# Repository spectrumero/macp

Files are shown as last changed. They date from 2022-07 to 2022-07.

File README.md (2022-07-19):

# ZX Make-a-Chip Pro

Back in the day, there was some software for the Sinclair Spectrum (often
advertised today as "VERY R@RE!!!!11" on eBay) called Make-a-Chip, by
Icognito Software Ltd. It waas a circuit simulator that allowed you to
build simple logic circuits with digital gates (AND, OR, NAND, NOR).

Today, of course, we can go many steps better; we have the FPGA (field
programmable gate array) to play with, and we can realise our own designs,
right up to entire systems on a chip.

2022 is the 40th anniversary of the launch of the Sinclair Spectrum, and
this project is something to celebrate that.

The ZX Make-a-Chip Pro is a board with a Lattice iCE40-HX4K FPGA with
all the level shifting required to connect to a Sinclair Spectrum.
It's designed to work with the open source IceStorm toolchain for
the FPGA used (but will no doubt work just fine with the Lattice
proprietary toolchain, too). Aside from the FPGA, it also has some
static ram (128k x 8, 256k x 8 or 512k x 8), the serial flash to 
hold the FPGA's "gateware" (with room left over for other uses),
a crystal oscillator, interface electronics for the 3.3v to 5v level
translation, and 25 GPIOs for connecting to other things.

## The PCB

A 4-layer PCB. This has been successfully made using PCBWay.

## Major parts

The FPGA is an iCE40-HX4K-TQ144. Unfortunately the HX1K has a sufficiently
different pinout that it won't work. When using arachne-pnr/nextpnr during
place and route, select "8k" as the device and "tq144:4k" as the package.
(In reality, the die in this chip is an HX8K)

Any JEDEC compliant SPI flash chip will work but it **must** support
the page program command. Check the datasheet before you commit to a chip.
While flash that doesn't support paged write will work, you won't be able
to program it with the `iceprog` tool - at least without modifying it to
work with a chip that doesn't support the page program command (and it's
doubtful you will be able to make it work at all with the Lattice
proprietary IDE).

Look for support for 'PP' (command 0x02) in the chip's datasheet.
The chip must also support 64kb block erase.

The gateware requires three 64kb blocks. This gets written to the first
three 64kb blocks. Remaining space in the flash may be used for projects 
(e.g. code), so as long as the flash is bigger than 192kbytes, it's good 
enough.

The RAM is on the 3.3v side of the board, so ensure that the static RAM
works with 3.3v (there are still quite a few 5v static RAM chips that won't
go down to 3.3v). The faster the better. If you only use the static RAM
for the Spectrum side then you can pretty much use any chip you please,
but if you're going to implement a second processor on the FPGA, you
probably want something fairly fast (10ns is available).

The crystal oscillator I use is 25MHz. If you choose a different value,
it's worth checking that it fits in the input limits of the FPGA's
PLL.

The remainder of the devices on the board should be pretty widely availble.

## Special symbols

There are two symbols unique to the project: the ZX edge connector
(designed for through hole mounting) and a schematic symbol for the
74ALVC164245PVG bus translator. The edge connector also has an associated
PCB footprint. See the local-lib directory.

## Programming other parts of the flash with iceprog

The icestorm toolchain's `iceprog` program can do more than just write
the gateware to the flash chip. You can supply it an offset, for example
if you want to store ROM code that will be used later by the FPGA
or copied to RAM, or a FatFS filesystem:

`iceprog -0 0x30000 file.bin`

to write the contents of a file from 0x30000 (the 64k block immediately
following the gateware).

## Recommended programming hardware

The Adafruit FT232H board works well (any similar board with this FTDI
chip should work with `iceprog`). Connect it as follows:

```
D0 -> SCK
D1 -> SDO
D2 -> SDI
D3 (not connected)
D4 -> SS
D5 (not connected)
D6 -> CDONE
D7 -> CRESET
```

You may need to invoke `iceprog` as follows:

`iceprog -d i:0x0403:0x6014 <filename>`

...if it fails to find your FT232H breakout board. (You may need `sudo`
as well).

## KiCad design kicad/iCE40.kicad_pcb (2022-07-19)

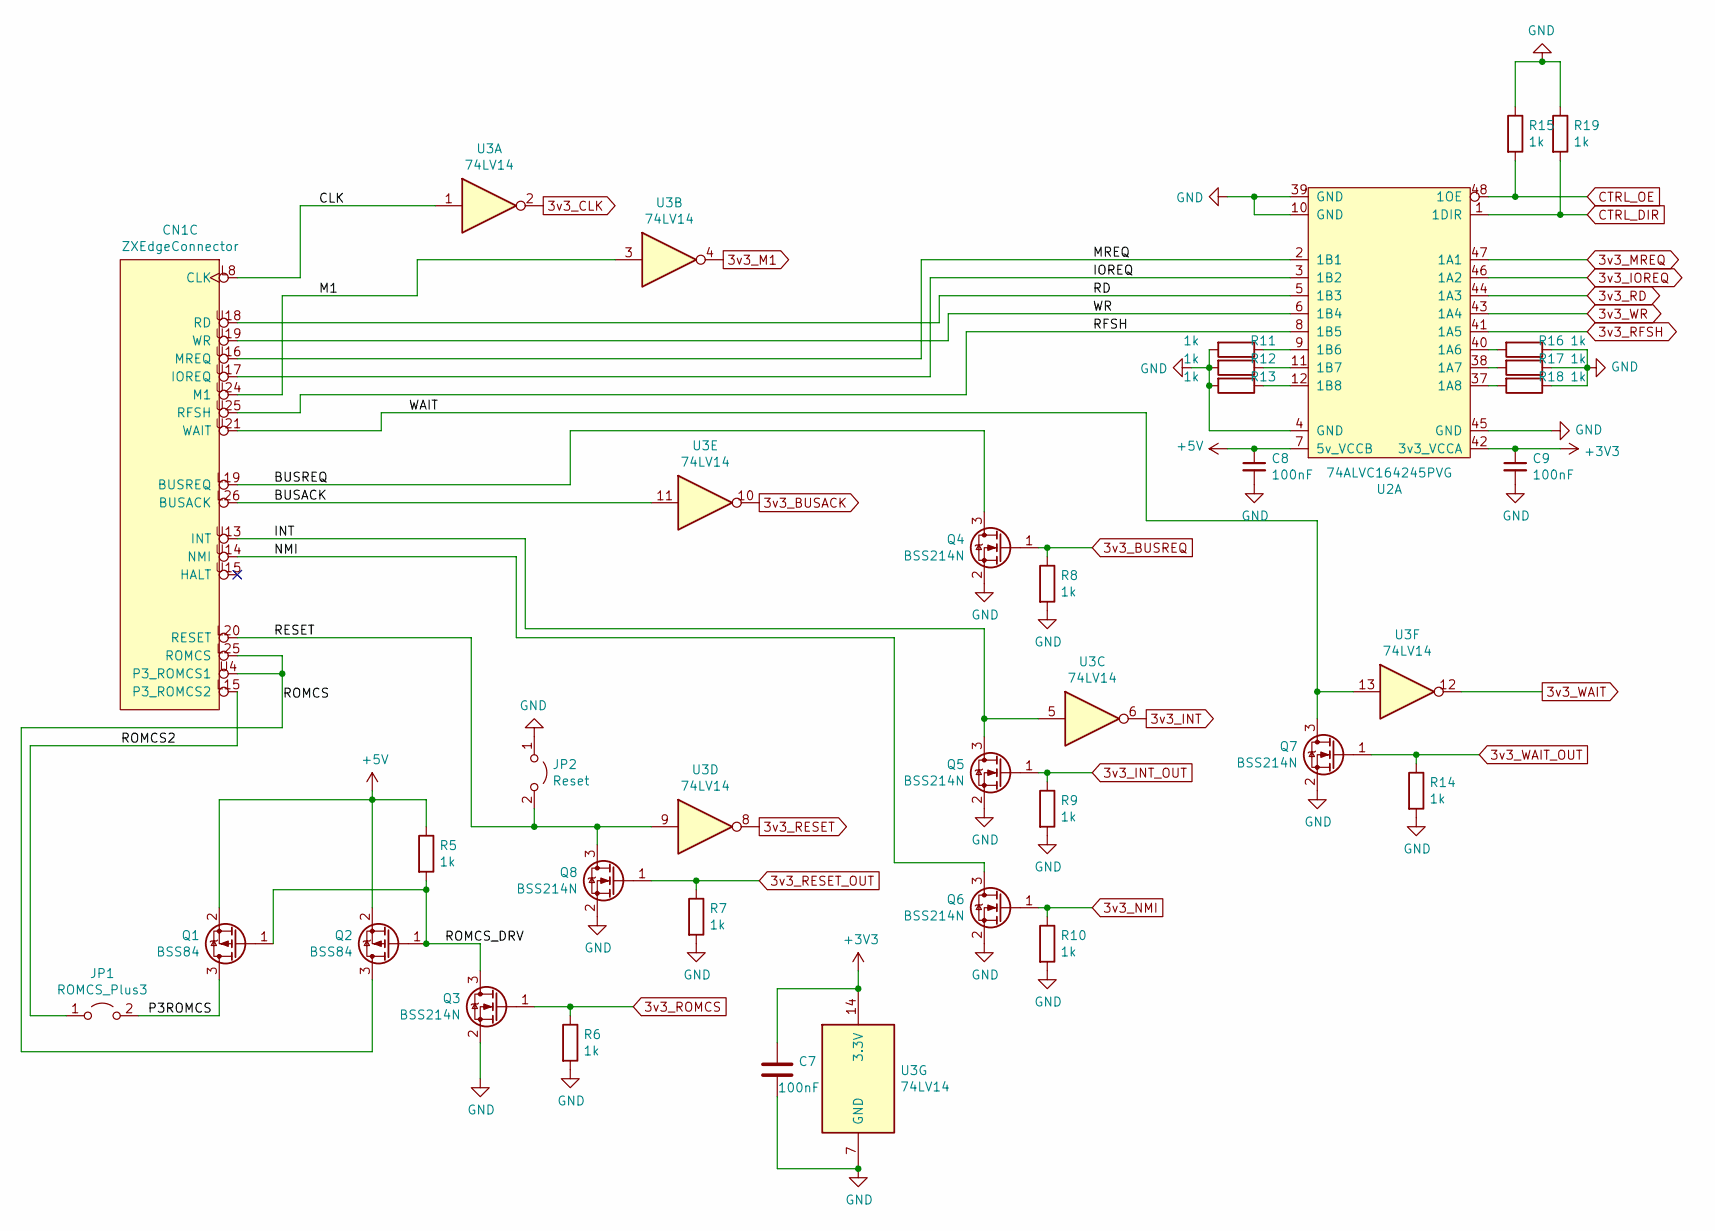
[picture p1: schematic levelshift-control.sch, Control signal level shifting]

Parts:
C7, C8, C9: 100nF; C_0603_1608Metric_Pad1.08x0.95mm_HandSolder
CN1: ZXEdgeConnector
JP1: ROMCS_Plus3; PinHeader_1x02_P2.54mm_Vertical
JP2: Reset; PinHeader_1x02_P2.54mm_Vertical
Q1, Q2: BSS84; SOT-23
Q3, Q4, Q5, Q6, Q7, Q8: BSS214N; SOT-23
R5, R6, R7, R8, R9, R10, R11, R12, R13, R14, R15, R16, R17, R18, R19: 1k; R_0603_1608Metric_Pad0.98x0.95mm_HandSolder
U2: 74ALVC164245PVG; SSOP-48_7.5x15.9mm_P0.635mm
U3: 74LV14; SOIC-14_3.9x8.7mm_P1.27mm

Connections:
3v3_BUSACK: U3.10; also elsewhere on the board
3v3_BUSREQ: Q4.1 (G), R8.1; also elsewhere on the board
3v3_CLK: U3.2; also elsewhere on the board
3v3_INT: U3.6; also elsewhere on the board
3v3_INT_OUT: Q5.1 (G), R9.1; also elsewhere on the board
3v3_IOREQ: U2.46 (1A2); also elsewhere on the board
3v3_M1: U3.4; also elsewhere on the board
3v3_MREQ: U2.47 (1A1); also elsewhere on the board
3v3_NMI: Q6.1 (G), R10.1; also elsewhere on the board
3v3_RD: U2.44 (1A3); also elsewhere on the board
3v3_RESET: U3.8; also elsewhere on the board
3v3_RESET_OUT: Q8.1 (G), R7.1; also elsewhere on the board
3v3_RFSH: U2.41 (1A5); also elsewhere on the board
3v3_ROMCS: Q3.1 (G), R6.1; also elsewhere on the board
3v3_WAIT: U3.12; also elsewhere on the board
3v3_WAIT_OUT: Q7.1 (G), R14.1; also elsewhere on the board
3v3_WR: U2.43 (1A4); also elsewhere on the board
+3V3: C7.1, C9.1, U2.42 (3v3_VCCA), U3.14 (3.3V); also elsewhere on the board
+5V: C8.1, Q1.2 (S), Q2.2 (S), R5.1, U2.7 (5v_VCCB); also elsewhere on the board
/levelshift-control/BUSACK: CN1.L26 (BUSACK), U3.11
/levelshift-control/BUSREQ: CN1.L19 (BUSREQ), Q4.3 (D)
/levelshift-control/CLK: CN1.L8 (CLK), U3.1
/levelshift-control/INT: CN1.U13 (INT), Q5.3 (D), U3.5
/levelshift-control/IOREQ: CN1.U17 (IOREQ), U2.3 (1B2)
/levelshift-control/M1: CN1.U24 (M1), U3.3
/levelshift-control/MREQ: CN1.U16 (MREQ), U2.2 (1B1)
/levelshift-control/NMI: CN1.U14 (NMI), Q6.3 (D)
/levelshift-control/P3ROMCS: JP1.2 (B), Q1.3 (D)
/levelshift-control/RD: CN1.U18 (RD), U2.5 (1B3)
/levelshift-control/RESET: CN1.L20 (RESET), JP2.2 (B), Q8.3 (D), U3.9
/levelshift-control/RFSH: CN1.U25 (RFSH), U2.8 (1B5)
/levelshift-control/ROMCS: CN1.L25 (ROMCS), CN1.U4 (P3_ROMCS1), Q2.3 (D)
/levelshift-control/ROMCS2: CN1.L15 (P3_ROMCS2), JP1.1 (A)
/levelshift-control/ROMCS_DRV: Q1.1 (G), Q2.1 (G), Q3.3 (D), R5.2
/levelshift-control/WAIT: CN1.U21 (WAIT), Q7.3 (D), U3.13
/levelshift-control/WR: CN1.U19 (WR), U2.6 (1B4)
CTRL_DIR: R19.2, U2.1 (1DIR); also elsewhere on the board
CTRL_OE: R15.2, U2.48 (1OE); also elsewhere on the board
GND: C7.2, C8.2, C9.2, JP2.1 (A), Q3.2 (S), Q4.2 (S), Q5.2 (S), Q6.2 (S), Q7.2 (S), Q8.2 (S), R6.2, R7.2, R8.2, R9.2, R10.2, R11.2, R12.2, R13.2, R14.2, R15.1, R16.1, R17.1, R18.1, R19.1, U2.4 (GND), U2.10 (GND), U2.39 (GND), U2.45 (GND), U3.7 (GND); also elsewhere on the board
unnamed: R11.1, U2.9 (1B6)
unnamed: R12.1, U2.11 (1B7)
unnamed: R13.1, U2.12 (1B8)
unnamed: R16.2, U2.40 (1A6)
unnamed: R17.2, U2.38 (1A7)
unnamed: R18.2, U2.37 (1A8)

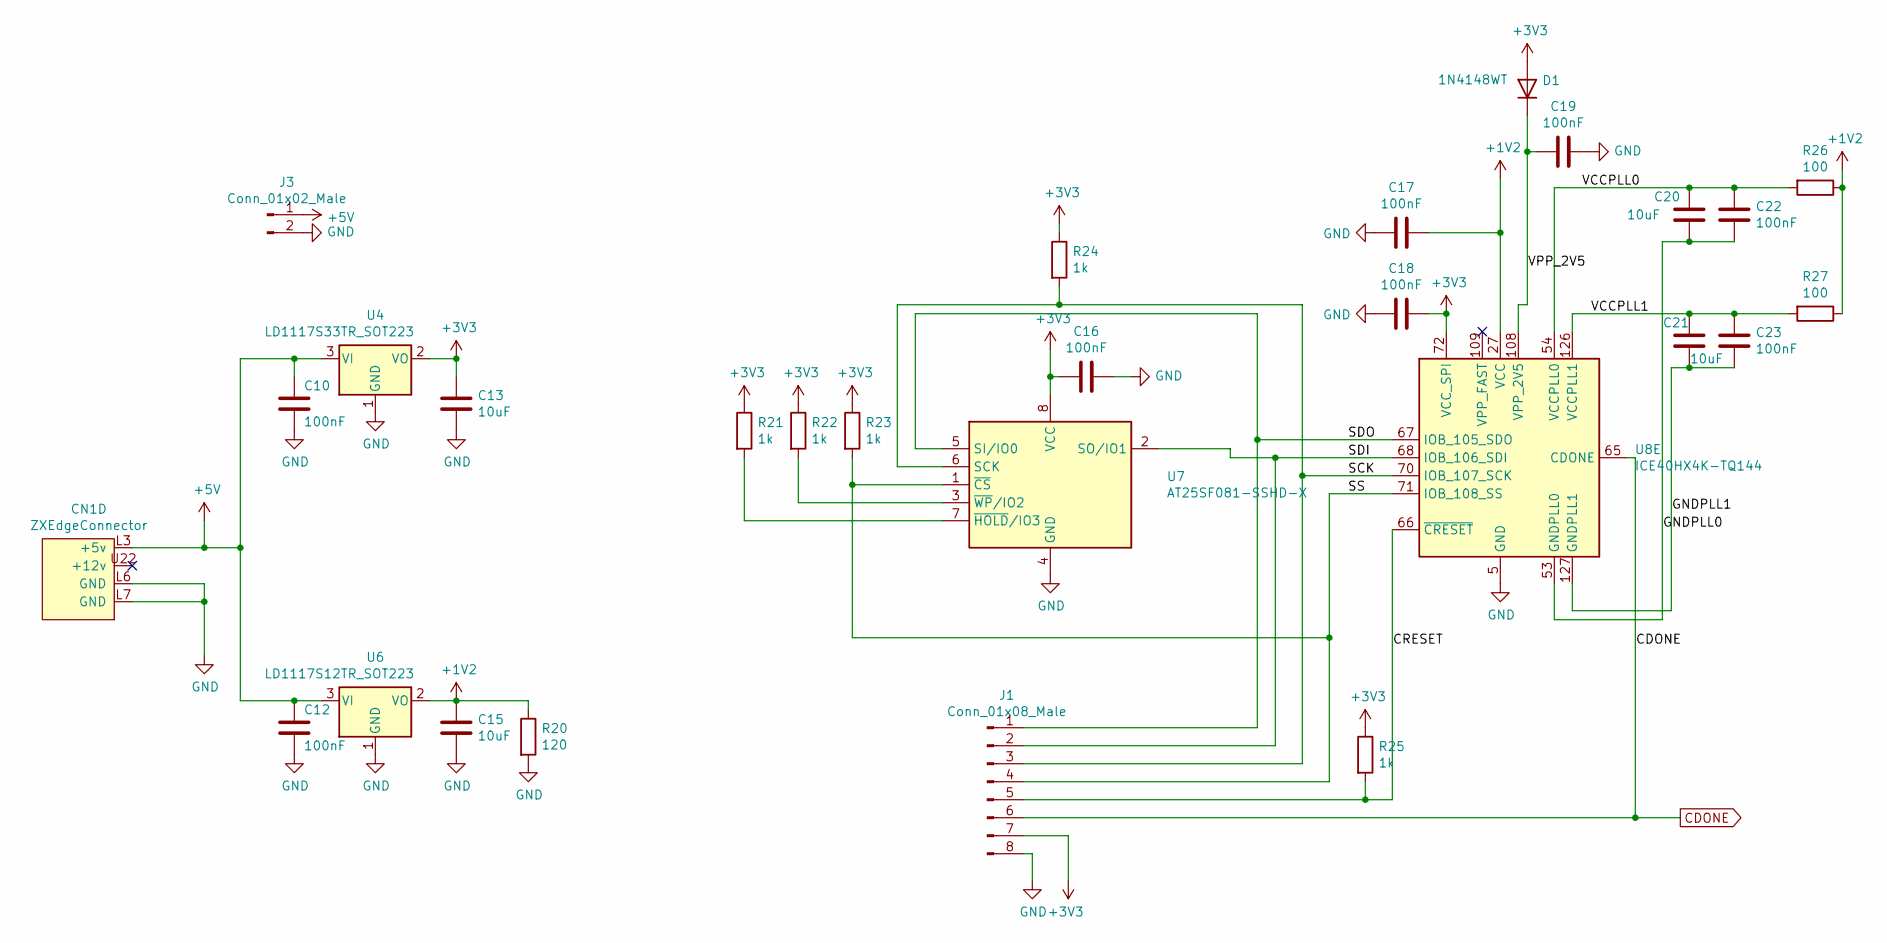
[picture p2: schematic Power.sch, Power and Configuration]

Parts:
C10, C12, C16, C17, C18, C19, C22, C23: 100nF; C_0603_1608Metric_Pad1.08x0.95mm_HandSolder
C13, C15, C20, C21: 10uF; C_0805_2012Metric_Pad1.18x1.45mm_HandSolder
CN1: ZXEdgeConnector
D1: 1N4148WT; D_SOD-523
J1: Conn_01x08_Male; PinHeader_1x08_P2.54mm_Vertical
J3: Conn_01x02_Male; PinHeader_1x02_P2.54mm_Vertical
R20: 120; R_0603_1608Metric_Pad0.98x0.95mm_HandSolder
R21, R22, R23, R24, R25: 1k; R_0603_1608Metric_Pad0.98x0.95mm_HandSolder
R26, R27: 100; R_0603_1608Metric_Pad0.98x0.95mm_HandSolder
U4: LD1117S33TR_SOT223; SOT-223-3_TabPin2
U6: LD1117S12TR_SOT223; SOT-223-3_TabPin2
U7: AT25SF081-SSHD-X; SOIC-8_3.9x4.9mm_P1.27mm
U8: ICE40HX4K-TQ144; TQFP-144_20x20mm_P0.5mm

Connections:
+1V2: C15.1, C17.1, R20.1, R26.1, R27.1, U6.2 (VO), U8.27 (VCC), U8.40 (VCC), U8.92 (VCC), U8.111 (VCC)
+3V3: C13.1, C16.2, C18.1, D1.2 (A), J1.7, R21.1, R22.1, R23.1, R24.1, R25.1, U4.2 (VO), U7.8 (VCC), U8.72 (VCC_SPI); also elsewhere on the board
+5V: C10.1, C12.1, CN1.L3 (+5v), J3.1, U4.3 (VI), U6.3 (VI); also elsewhere on the board
/Power And Config/CRESET: J1.5, R25.2, U8.66 (~CRESET)
/Power And Config/GNDPLL0: C20.2, C22.2, U8.53 (GNDPLL0)
/Power And Config/GNDPLL1: C21.2, C23.2, U8.127 (GNDPLL1)
/Power And Config/SCK: J1.3, R24.2, U7.6 (SCK), U8.70 (IOB_107_SCK)
/Power And Config/SDI: J1.2, U7.2 (SO/IO1), U8.68 (IOB_106_SDI)
/Power And Config/SDO: J1.1, U7.5 (SI/IO0), U8.67 (IOB_105_SDO)
/Power And Config/SS: J1.4, R23.2, U7.1 (~CS), U8.71 (IOB_108_SS)
/Power And Config/VCCPLL0: C20.1, C22.1, R26.2, U8.54 (VCCPLL0)
/Power And Config/VCCPLL1: C21.1, C23.1, R27.2, U8.126 (VCCPLL1)
/Power And Config/VPP_2V5: C19.2, D1.1 (K), U8.108 (VPP_2V5)
CDONE: J1.6, U8.65 (CDONE)
GND: C10.2, C12.2, C13.2, C15.2, C16.1, C17.2, C18.2, C19.1, CN1.L6 (GND), CN1.L7 (GND), J1.8, J3.2, R20.2, U4.1 (GND), U6.1 (GND), U7.4 (GND), U8.5 (GND), U8.13 (GND), U8.14 (GND), U8.59 (GND), U8.69 (GND), U8.86 (GND), U8.103 (GND), U8.132 (GND), U8.140 (GND); also elsewhere on the board
unnamed: R21.2, U7.7 (~HOLD~/IO3)
unnamed: R22.2, U7.3 (~WP~/IO2)

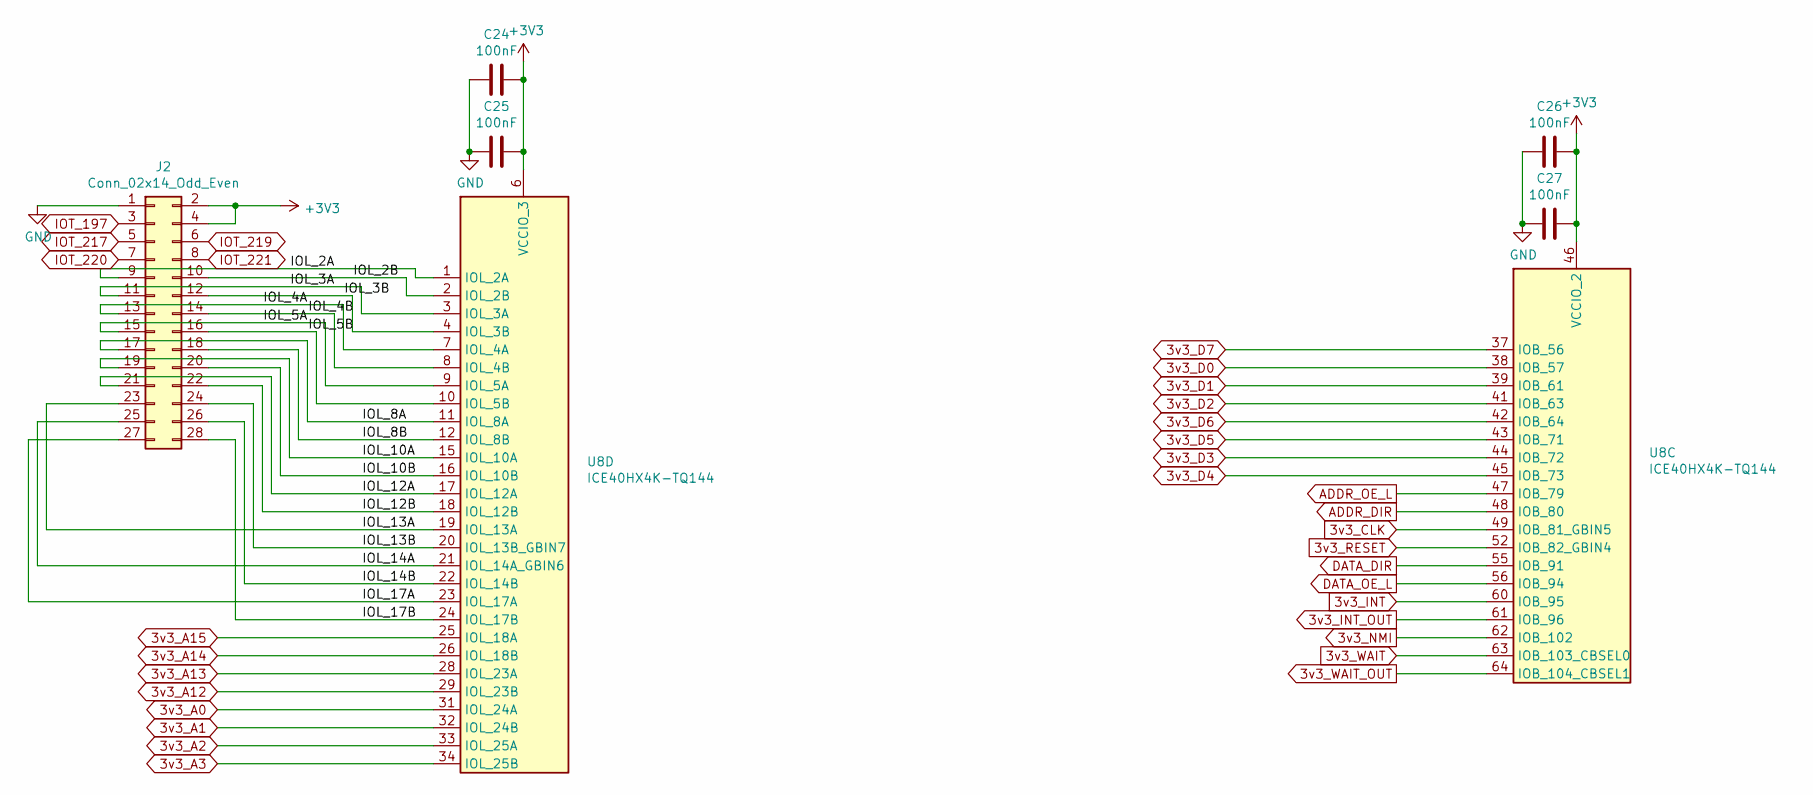
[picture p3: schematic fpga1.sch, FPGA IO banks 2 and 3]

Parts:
C24, C25, C26, C27: 100nF; C_0603_1608Metric_Pad1.08x0.95mm_HandSolder
J2: Conn_02x14_Odd_Even; PinHeader_2x14_P2.54mm_Vertical
U8: ICE40HX4K-TQ144; TQFP-144_20x20mm_P0.5mm

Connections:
3v3_A0: U8.31 (IOL_24A); also elsewhere on the board
3v3_A1: U8.32 (IOL_24B); also elsewhere on the board
3v3_A2: U8.33 (IOL_25A); also elsewhere on the board
3v3_A3: U8.34 (IOL_25B); also elsewhere on the board
3v3_A12: U8.29 (IOL_23B); also elsewhere on the board
3v3_A13: U8.28 (IOL_23A); also elsewhere on the board
3v3_A14: U8.26 (IOL_18B); also elsewhere on the board
3v3_A15: U8.25 (IOL_18A); also elsewhere on the board
3v3_CLK: U8.49 (IOB_81_GBIN5); also elsewhere on the board
3v3_D0: U8.38 (IOB_57); also elsewhere on the board
3v3_D1: U8.39 (IOB_61); also elsewhere on the board
3v3_D2: U8.41 (IOB_63); also elsewhere on the board
3v3_D3: U8.44 (IOB_72); also elsewhere on the board
3v3_D4: U8.45 (IOB_73); also elsewhere on the board
3v3_D5: U8.43 (IOB_71); also elsewhere on the board
3v3_D6: U8.42 (IOB_64); also elsewhere on the board
3v3_D7: U8.37 (IOB_56); also elsewhere on the board
3v3_INT: U8.60 (IOB_95); also elsewhere on the board
3v3_INT_OUT: U8.61 (IOB_96); also elsewhere on the board
3v3_NMI: U8.62 (IOB_102); also elsewhere on the board
3v3_RESET: U8.52 (IOB_82_GBIN4); also elsewhere on the board
3v3_WAIT: U8.63 (IOB_103_CBSEL0); also elsewhere on the board
3v3_WAIT_OUT: U8.64 (IOB_104_CBSEL1); also elsewhere on the board
+3V3: C24.1, C25.2, C26.1, C27.2, J2.2, J2.4, U8.6 (VCCIO_3), U8.30 (VCCIO_3), U8.46 (VCCIO_2), U8.57 (VCCIO_2); also elsewhere on the board
/FPGA1/IOL_2A: J2.9, U8.1 (IOL_2A)
/FPGA1/IOL_2B: J2.10, U8.2 (IOL_2B)
/FPGA1/IOL_3A: J2.11, U8.3 (IOL_3A)
/FPGA1/IOL_3B: J2.12, U8.4 (IOL_3B)
/FPGA1/IOL_4A: J2.13, U8.7 (IOL_4A)
/FPGA1/IOL_4B: J2.14, U8.8 (IOL_4B)
/FPGA1/IOL_5A: J2.15, U8.9 (IOL_5A)
/FPGA1/IOL_5B: J2.16, U8.10 (IOL_5B)
/FPGA1/IOL_8A: J2.17, U8.11 (IOL_8A)
/FPGA1/IOL_8B: J2.18, U8.12 (IOL_8B)
/FPGA1/IOL_10A: J2.19, U8.15 (IOL_10A)
/FPGA1/IOL_10B: J2.20, U8.16 (IOL_10B)
/FPGA1/IOL_12A: J2.21, U8.17 (IOL_12A)
/FPGA1/IOL_12B: J2.22, U8.18 (IOL_12B)
/FPGA1/IOL_13A: J2.23, U8.19 (IOL_13A)
/FPGA1/IOL_13B: J2.24, U8.20 (IOL_13B_GBIN7)
/FPGA1/IOL_14A: J2.25, U8.21 (IOL_14A_GBIN6)
/FPGA1/IOL_14B: J2.26, U8.22 (IOL_14B)
/FPGA1/IOL_17A: J2.27, U8.23 (IOL_17A)
/FPGA1/IOL_17B: J2.28, U8.24 (IOL_17B)
ADDR_DIR: U8.48 (IOB_80); also elsewhere on the board
ADDR_OE_L: U8.47 (IOB_79); also elsewhere on the board
DATA_DIR: U8.55 (IOB_91); also elsewhere on the board
DATA_OE_L: U8.56 (IOB_94); also elsewhere on the board
GND: C24.2, C25.1, C26.2, C27.1, J2.1; also elsewhere on the board
IOT_197: J2.3; also elsewhere on the board
IOT_217: J2.5; also elsewhere on the board
IOT_219: J2.6; also elsewhere on the board
IOT_220: J2.7; also elsewhere on the board
IOT_221: J2.8; also elsewhere on the board

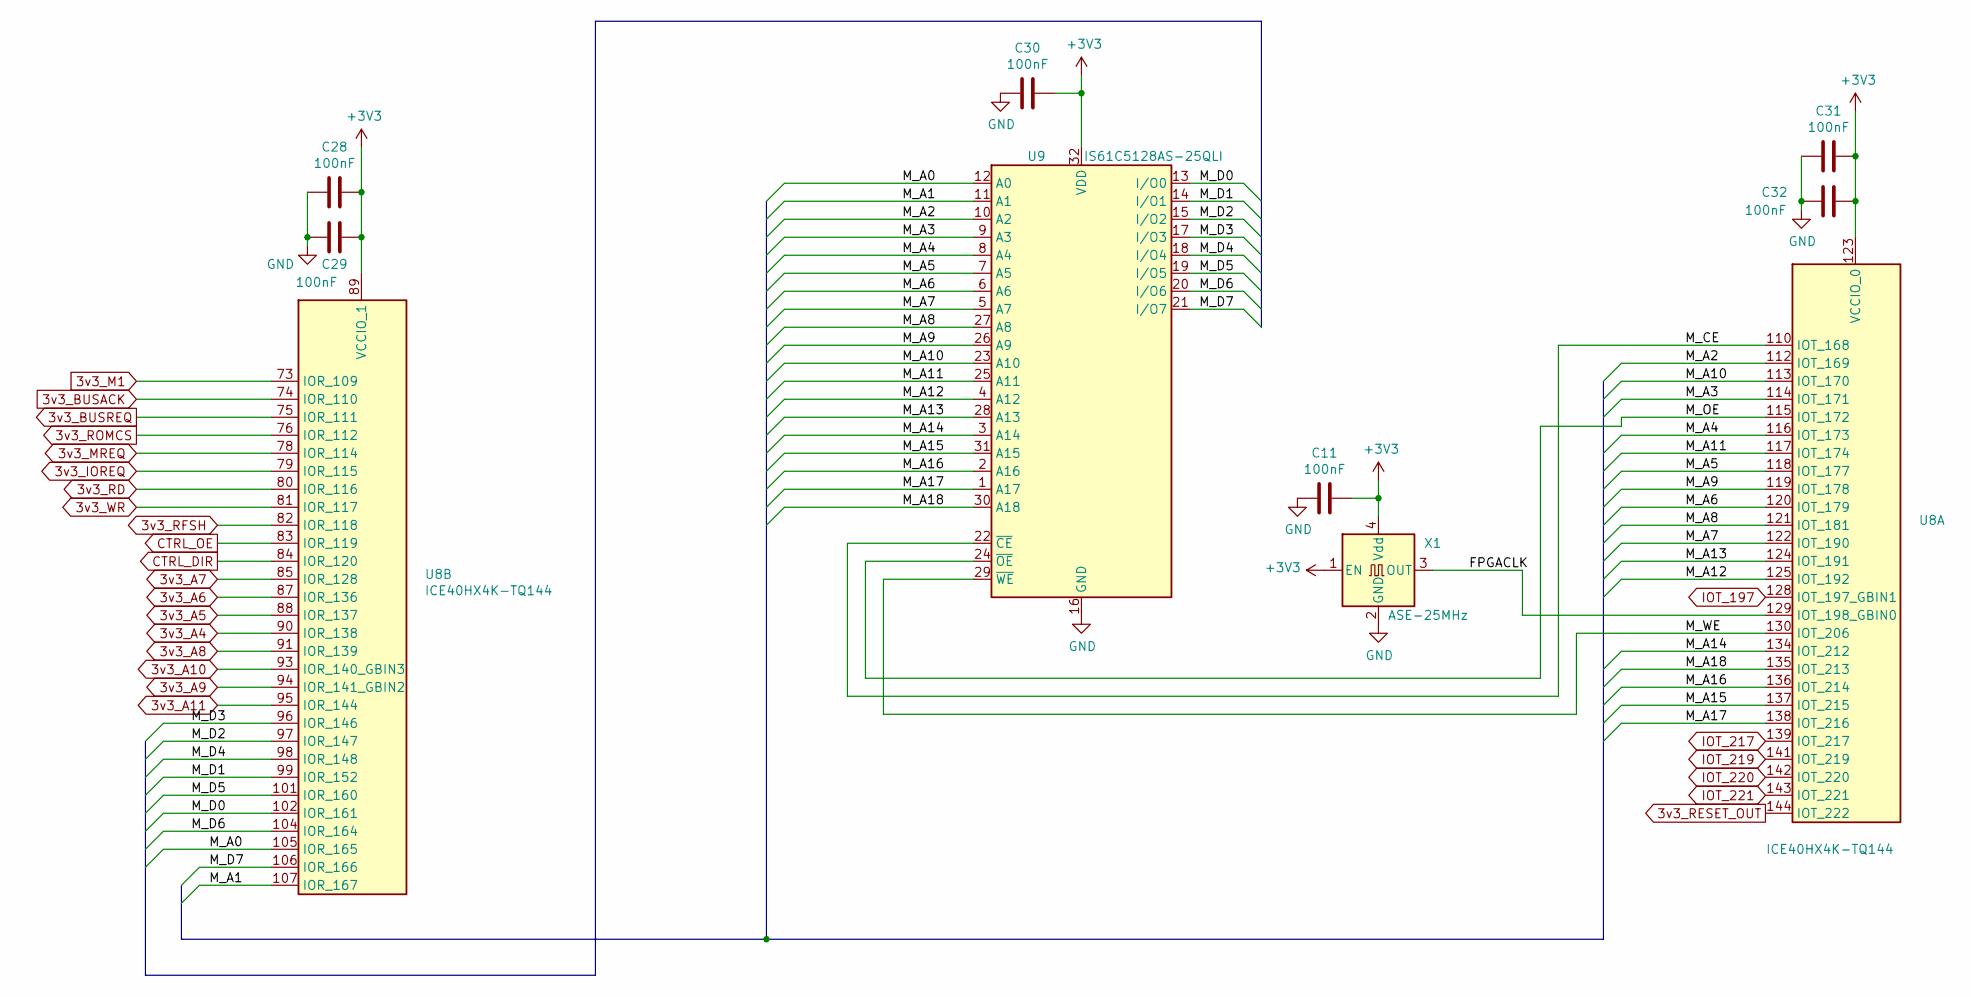
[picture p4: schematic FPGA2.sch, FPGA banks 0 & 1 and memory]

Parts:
C11, C28, C29, C30, C31, C32: 100nF; C_0603_1608Metric_Pad1.08x0.95mm_HandSolder
U8: ICE40HX4K-TQ144; TQFP-144_20x20mm_P0.5mm
U9: IS61C5128AS-25QLI; SSOP-32_11.305x20.495mm_P1.27mm
X1: ASE-25MHz; Oscillator_SMD_Abracon_ASE-4Pin_3.2x2.5mm

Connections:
3v3_A4: U8.90 (IOR_138); also elsewhere on the board
3v3_A5: U8.88 (IOR_137); also elsewhere on the board
3v3_A6: U8.87 (IOR_136); also elsewhere on the board
3v3_A7: U8.85 (IOR_128); also elsewhere on the board
3v3_A8: U8.91 (IOR_139); also elsewhere on the board
3v3_A9: U8.94 (IOR_141_GBIN2); also elsewhere on the board
3v3_A10: U8.93 (IOR_140_GBIN3); also elsewhere on the board
3v3_A11: U8.95 (IOR_144); also elsewhere on the board
3v3_BUSACK: U8.74 (IOR_110); also elsewhere on the board
3v3_BUSREQ: U8.75 (IOR_111); also elsewhere on the board
3v3_IOREQ: U8.79 (IOR_115); also elsewhere on the board
3v3_M1: U8.73 (IOR_109); also elsewhere on the board
3v3_MREQ: U8.78 (IOR_114); also elsewhere on the board
3v3_RD: U8.80 (IOR_116); also elsewhere on the board
3v3_RESET_OUT: U8.144 (IOT_222); also elsewhere on the board
3v3_RFSH: U8.82 (IOR_118); also elsewhere on the board
3v3_ROMCS: U8.76 (IOR_112); also elsewhere on the board
3v3_WR: U8.81 (IOR_117); also elsewhere on the board
+3V3: C11.1, C28.1, C29.1, C30.1, C31.1, C32.1, U8.89 (VCCIO_1), U8.100 (VCCIO_1), U8.123 (VCCIO_0), U8.131 (VCCIO_0), U9.32 (VDD), X1.1 (EN), X1.4 (Vdd); also elsewhere on the board
/FPGA2/FPGACLK: U8.129 (IOT_198_GBIN0), X1.3 (OUT)
/FPGA2/M_A0: U8.105 (IOR_165), U9.12 (A0)
/FPGA2/M_A1: U8.107 (IOR_167), U9.11 (A1)
/FPGA2/M_A2: U8.112 (IOT_169), U9.10 (A2)
/FPGA2/M_A3: U8.114 (IOT_171), U9.9 (A3)
/FPGA2/M_A4: U8.116 (IOT_173), U9.8 (A4)
/FPGA2/M_A5: U8.118 (IOT_177), U9.7 (A5)
/FPGA2/M_A6: U8.120 (IOT_179), U9.6 (A6)
/FPGA2/M_A7: U8.122 (IOT_190), U9.5 (A7)
/FPGA2/M_A8: U8.121 (IOT_181), U9.27 (A8)
/FPGA2/M_A9: U8.119 (IOT_178), U9.26 (A9)
/FPGA2/M_A10: U8.113 (IOT_170), U9.23 (A10)
/FPGA2/M_A11: U8.117 (IOT_174), U9.25 (A11)
/FPGA2/M_A12: U8.125 (IOT_192), U9.4 (A12)
/FPGA2/M_A13: U8.124 (IOT_191), U9.28 (A13)
/FPGA2/M_A14: U8.134 (IOT_212), U9.3 (A14)
/FPGA2/M_A15: U8.137 (IOT_215), U9.31 (A15)
/FPGA2/M_A16: U8.136 (IOT_214), U9.2 (A16)
/FPGA2/M_A17: U8.138 (IOT_216), U9.1 (A17)
/FPGA2/M_A18: U8.135 (IOT_213), U9.30 (A18)
/FPGA2/M_CE: U8.110 (IOT_168), U9.22 (~CE)
/FPGA2/M_D0: U8.102 (IOR_161), U9.13 (I/O0)
/FPGA2/M_D1: U8.99 (IOR_152), U9.14 (I/O1)
/FPGA2/M_D2: U8.97 (IOR_147), U9.15 (I/O2)
/FPGA2/M_D3: U8.96 (IOR_146), U9.17 (I/O3)
/FPGA2/M_D4: U8.98 (IOR_148), U9.18 (I/O4)
/FPGA2/M_D5: U8.101 (IOR_160), U9.19 (I/O5)
/FPGA2/M_D6: U8.104 (IOR_164), U9.20 (I/O6)
/FPGA2/M_D7: U8.106 (IOR_166), U9.21 (I/O7)
/FPGA2/M_OE: U8.115 (IOT_172), U9.24 (~OE)
/FPGA2/M_WE: U8.130 (IOT_206), U9.29 (~WE)
CTRL_DIR: U8.84 (IOR_120); also elsewhere on the board
CTRL_OE: U8.83 (IOR_119); also elsewhere on the board
GND: C11.2, C28.2, C29.2, C30.2, C31.2, C32.2, U9.16 (GND), X1.2 (GND); also elsewhere on the board
IOT_197: U8.128 (IOT_197_GBIN1); also elsewhere on the board
IOT_217: U8.139 (IOT_217); also elsewhere on the board
IOT_219: U8.141 (IOT_219); also elsewhere on the board
IOT_220: U8.142 (IOT_220); also elsewhere on the board
IOT_221: U8.143 (IOT_221); also elsewhere on the board

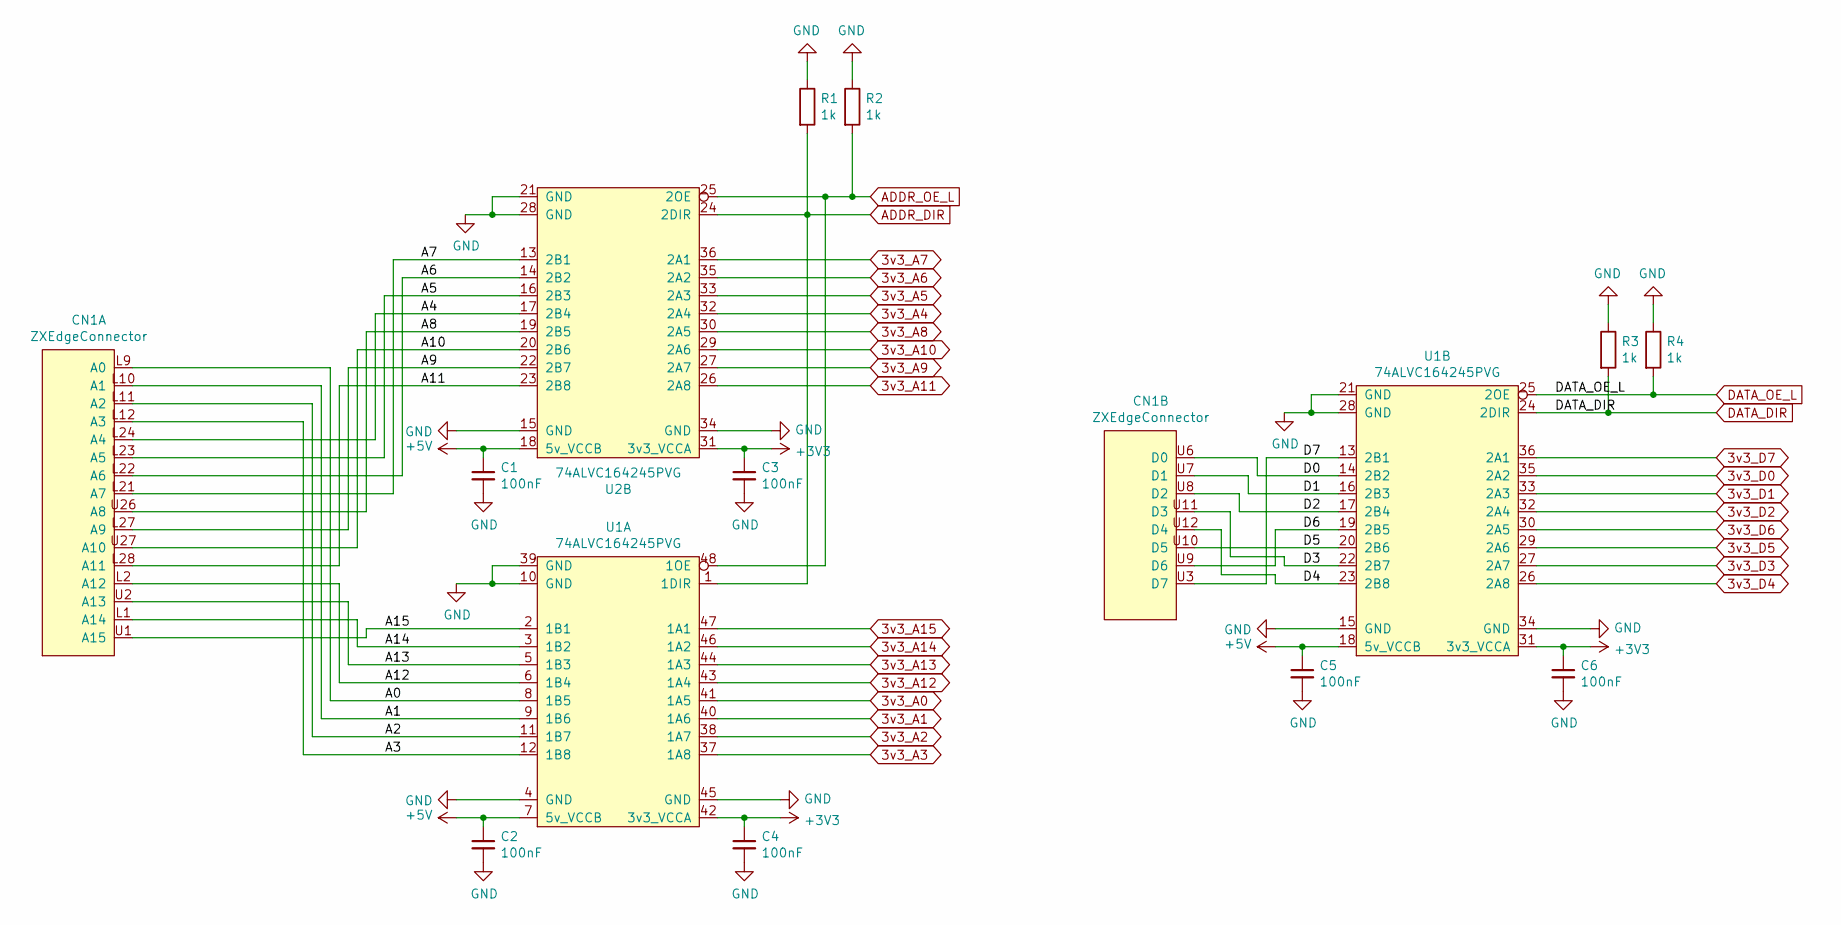
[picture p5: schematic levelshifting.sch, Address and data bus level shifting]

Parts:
C1, C2, C3, C4, C5, C6: 100nF; C_0603_1608Metric_Pad1.08x0.95mm_HandSolder
CN1: ZXEdgeConnector
R1, R2, R3, R4: 1k; R_0603_1608Metric_Pad0.98x0.95mm_HandSolder
U1, U2: 74ALVC164245PVG; SSOP-48_7.5x15.9mm_P0.635mm

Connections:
3v3_A0: U1.41 (1A5); also elsewhere on the board
3v3_A1: U1.40 (1A6); also elsewhere on the board
3v3_A2: U1.38 (1A7); also elsewhere on the board
3v3_A3: U1.37 (1A8); also elsewhere on the board
3v3_A4: U2.32 (2A4); also elsewhere on the board
3v3_A5: U2.33 (2A3); also elsewhere on the board
3v3_A6: U2.35 (2A2); also elsewhere on the board
3v3_A7: U2.36 (2A1); also elsewhere on the board
3v3_A8: U2.30 (2A5); also elsewhere on the board
3v3_A9: U2.27 (2A7); also elsewhere on the board
3v3_A10: U2.29 (2A6); also elsewhere on the board
3v3_A11: U2.26 (2A8); also elsewhere on the board
3v3_A12: U1.43 (1A4); also elsewhere on the board
3v3_A13: U1.44 (1A3); also elsewhere on the board
3v3_A14: U1.46 (1A2); also elsewhere on the board
3v3_A15: U1.47 (1A1); also elsewhere on the board
3v3_D0: U1.35 (2A2); also elsewhere on the board
3v3_D1: U1.33 (2A3); also elsewhere on the board
3v3_D2: U1.32 (2A4); also elsewhere on the board
3v3_D3: U1.27 (2A7); also elsewhere on the board
3v3_D4: U1.26 (2A8); also elsewhere on the board
3v3_D5: U1.29 (2A6); also elsewhere on the board
3v3_D6: U1.30 (2A5); also elsewhere on the board
3v3_D7: U1.36 (2A1); also elsewhere on the board
+3V3: C3.1, C4.1, C6.1, U1.31 (3v3_VCCA), U1.42 (3v3_VCCA), U2.31 (3v3_VCCA); also elsewhere on the board
+5V: C1.1, C2.1, C5.1, U1.7 (5v_VCCB), U1.18 (5v_VCCB), U2.18 (5v_VCCB); also elsewhere on the board
/levelshifting/A0: CN1.L9 (A0), U1.8 (1B5)
/levelshifting/A1: CN1.L10 (A1), U1.9 (1B6)
/levelshifting/A2: CN1.L11 (A2), U1.11 (1B7)
/levelshifting/A3: CN1.L12 (A3), U1.12 (1B8)
/levelshifting/A4: CN1.L24 (A4), U2.17 (2B4)
/levelshifting/A5: CN1.L23 (A5), U2.16 (2B3)
/levelshifting/A6: CN1.L22 (A6), U2.14 (2B2)
/levelshifting/A7: CN1.L21 (A7), U2.13 (2B1)
/levelshifting/A8: CN1.U26 (A8), U2.19 (2B5)
/levelshifting/A9: CN1.L27 (A9), U2.22 (2B7)
/levelshifting/A10: CN1.U27 (A10), U2.20 (2B6)
/levelshifting/A11: CN1.L28 (A11), U2.23 (2B8)
/levelshifting/A12: CN1.L2 (A12), U1.6 (1B4)
/levelshifting/A13: CN1.U2 (A13), U1.5 (1B3)
/levelshifting/A14: CN1.L1 (A14), U1.3 (1B2)
/levelshifting/A15: CN1.U1 (A15), U1.2 (1B1)
/levelshifting/D0: CN1.U6 (D0), U1.14 (2B2)
/levelshifting/D1: CN1.U7 (D1), U1.16 (2B3)
/levelshifting/D2: CN1.U8 (D2), U1.17 (2B4)
/levelshifting/D3: CN1.U11 (D3), U1.22 (2B7)
/levelshifting/D4: CN1.U12 (D4), U1.23 (2B8)
/levelshifting/D5: CN1.U10 (D5), U1.20 (2B6)
/levelshifting/D6: CN1.U9 (D6), U1.19 (2B5)
/levelshifting/D7: CN1.U3 (D7), U1.13 (2B1)
ADDR_DIR: R1.2, U1.1 (1DIR), U2.24 (2DIR); also elsewhere on the board
ADDR_OE_L: R2.2, U1.48 (1OE), U2.25 (2OE); also elsewhere on the board
DATA_DIR: R3.2, U1.24 (2DIR); also elsewhere on the board
DATA_OE_L: R4.2, U1.25 (2OE); also elsewhere on the board
GND: C1.2, C2.2, C3.2, C4.2, C5.2, C6.2, R1.1, R2.1, R3.1, R4.1, U1.4 (GND), U1.10 (GND), U1.15 (GND), U1.21 (GND), U1.28 (GND), U1.34 (GND), U1.39 (GND), U1.45 (GND), U2.15 (GND), U2.21 (GND), U2.28 (GND), U2.34 (GND); also elsewhere on the board

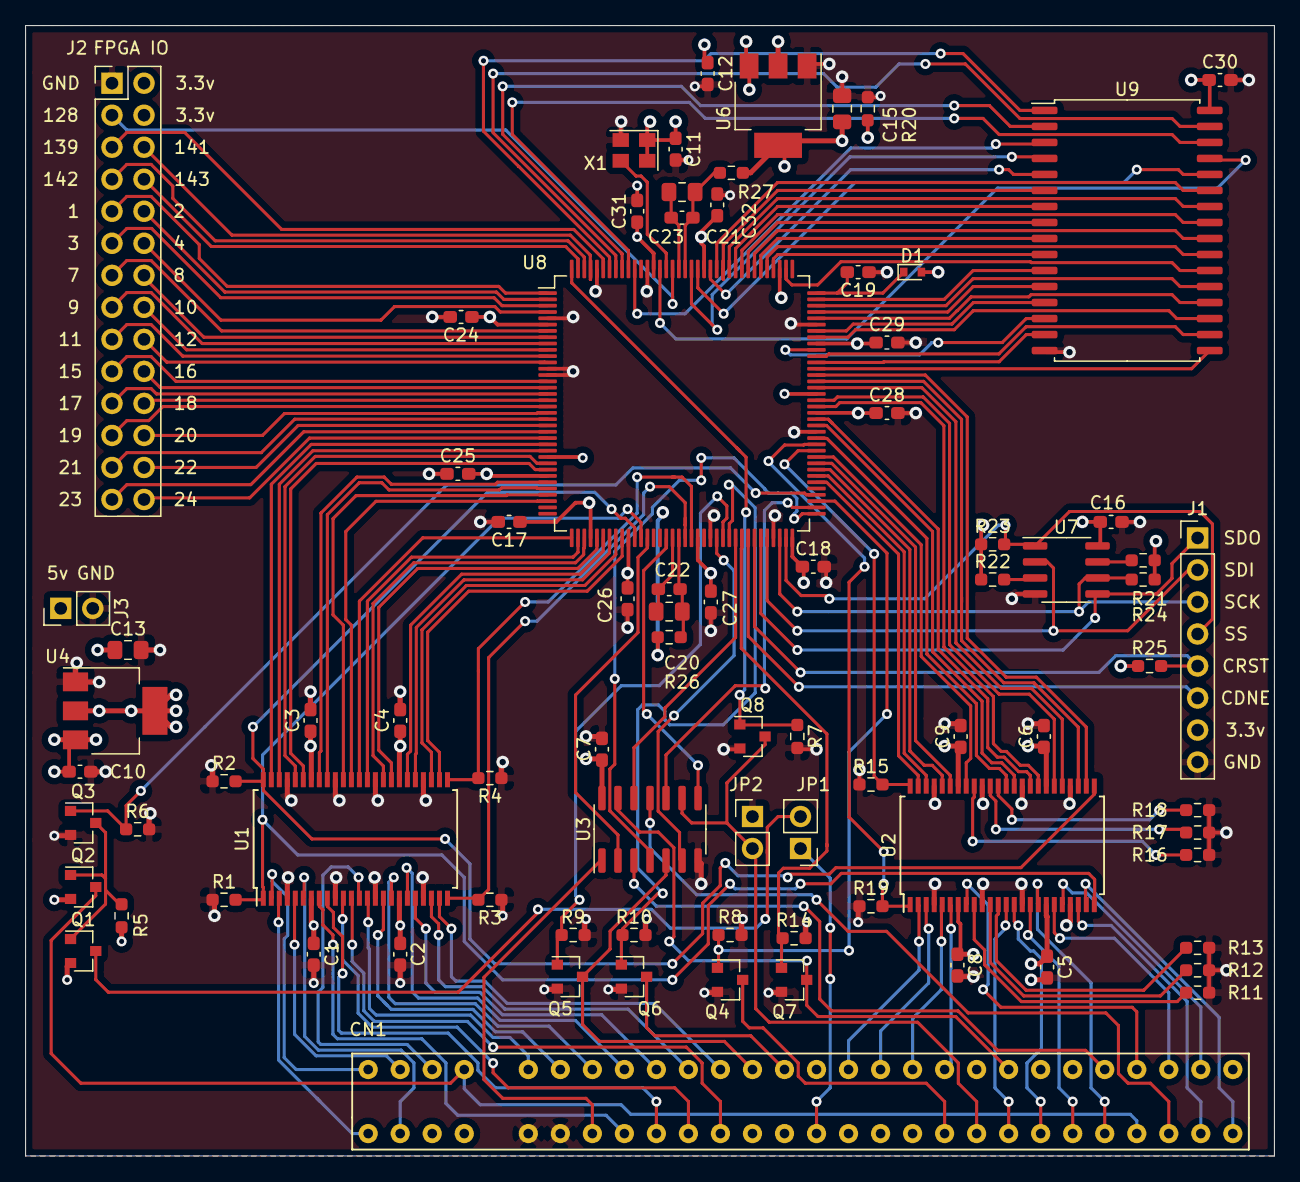
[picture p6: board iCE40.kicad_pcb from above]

Board: 4 copper layers, 99.1 x 89.7 mm, 82 parts (0 on the bottom side), 167 nets.
